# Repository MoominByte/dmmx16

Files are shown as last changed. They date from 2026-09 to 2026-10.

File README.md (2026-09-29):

# BenchScan DMMX16

BenchScan DMMX16 is a digital multimeter switching card inspired by the functional architecture of the SIGLENT SC1016. It provides 16 measurement channels: 12 multipurpose channels and 4 fuse-protected current channels.

## Project status

- Schematic revision: **DRAFT-1**
- File format: **KiCad 10**
- Hierarchical schematic converted and saved
- ERC: **0 errors and 18 off-grid warnings** from the custom MOSFET symbols
- PCB: **220 × 110 mm**, four copper layers, with all 113 footprints placed on the top side
- Preliminary placement completed; routing and manufacturing files have not started

This project is not ready for manufacturing.

## Opening the project

Open `BenchScan_DMMX16.kicad_pro` with KiCad 10. The modern root schematic is `BenchScan_DMMX16.kicad_sch`.

The legacy `.sch` files are retained as conversion sources. The earlier architecture-only draft is preserved under `archive/architecture-notes-draft0/`.

## Architecture

### Control

- Main module: Seeed Studio XIAO ESP32-C6, U1
- D0 / GPIO0: serial data `SER`
- D1 / GPIO1: shift clock `SRCLK`
- D2 / GPIO2: register clock `RCLK`
- D3 / GPIO21: active-low output enable `/OE`
- D4 / GPIO22: direct K17 control
- U2 and U3: two SN74HC595 shift registers powered by the XIAO 3.3 V output
- U2 controls K1-K8 and U3 controls K9-K16

Each relay is driven by a 2N7002K MOSFET with a 100 ohm series gate resistor, a 47 kohm gate pull-down, and a 1N4148W flyback diode. K17 uses the same driver circuit but receives its control signal directly from the XIAO.

### Measurement channels

| Connector | Channels | Purpose |
| --- | --- | --- |
| J1 | CH1-CH4 | Voltage, resistance, frequency, capacitance, diode, continuity, and temperature |
| J2 | CH5-CH8 | Multipurpose measurement and associated SENSE channels |
| J3 | CH9-CH12 | Multipurpose measurement and associated SENSE channels |
| J4 | CH13-CH16 | Current measurement, provisional 500 mA maximum |

Each J1-J4 connector has eight positions at 5.00 mm pitch: one `HI` and one `LO` terminal for each of its four channels.

### Switching

- K1-K16 use normally open contacts.
- K1-K6 route directly to `INPUT_HI` and `COM`.
- K7-K12 are routed through K17.
- With K17 de-energized, K7-K12 are routed to `INPUT_HI` and `COM`.
- With K17 energized, K7-K12 are routed to `SENSE_HI` and `SENSE_LO`.
- The four-wire pairs are CH1+CH7, CH2+CH8, CH3+CH9, CH4+CH10, CH5+CH11, and CH6+CH12.
- K13-K16 route the current channels to `CURRENT_HI` and `CURRENT_LO`.

Firmware must prevent multiple channels from being connected to the same destination bus at the same time, except for one valid four-wire pair.

### Current-channel protection

F1-F4 are Littelfuse `0451.500MRL` fast-acting 500 mA, 125 V fuses. They must not be replaced by 0.1 ohm resistors without a new circuit and safety analysis.

### DMM interface

J5 and the six banana jacks expose:

- `INPUT_HI`
- `COM`
- `SENSE_HI`
- `SENSE_LO`
- `CURRENT_HI`
- `CURRENT_LO`

R50 is a default-fitted 0 ohm link between `CURRENT_LO` and `COM`, with accessible test points planned on both sides.

### Power

- The XIAO is powered through its USB-C connector.
- The barrel jack supplies only the `+5V_RELAY` rail through F6 and Q19.
- USB, logic, and relay grounds are common.
- The external 5 V supply is not connected directly to the XIAO VBUS pin, preventing backfeed into USB.

## Schematic structure

- `01_power_control.kicad_sch`: XIAO, shift registers, and power supply
- `02_relay_drivers.kicad_sch`: 17 relay-coil drivers
- `03_voltage_channels.kicad_sch`: CH1-CH12 and normal/sense selection
- `04_current_dmm_interface.kicad_sch`: CH13-CH16, fuses, and DMM interface

Supporting documents:

- `BOM_AUDIT.md`: bill-of-materials review
- `CONNECTOR_PINOUT.csv`: J1-J4 pin assignments
- `SWITCHING_TRUTH_TABLE.md`: switching truth table
- `PLACEMENT_CONSTRAINTS.md`: mechanical and placement constraints
- `SC1016_REFERENCE.md`: SC1016 reference specifications
- `erc-placement.json`: latest automated ERC report
- `drc-placement.json`: preliminary placement DRC report (routing intentionally incomplete)
- `LIBRARY_SOURCES.md`: footprint provenance and manufacturer references

## Required before routing

1. Align the custom MOSFET symbol pins to eliminate the 18 ERC off-grid warnings.
2. Verify the gate, source, and drain pin mapping of Q1-Q19 against the selected SOT-23 footprint.
3. Mechanically verify the four project-created footprints against physical samples or manufacturer drawings before ordering boards.
4. Confirm voltage limits, creepage and clearance requirements, trace-width rules, and internal plane strategy.
5. Review and refine the preliminary placement, especially edge access and measurement-signal return paths.
6. Complete a manual schematic and PCB review before routing and manufacturing-output generation.

## Warning

The SC1016 ratings are used only as a functional reference. They do not certify the electrical limits of this board. A complete safety and manufacturability review is required before ordering PCBs.

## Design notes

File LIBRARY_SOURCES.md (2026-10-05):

# Component library sources

The project keeps the exact footprints used by the design in local KiCad libraries so the design remains reproducible.

| Part | Project library | Source | Notes |
|---|---|---|---|
| Phoenix Contact 1190370 | `BenchScan_Connectors.pretty` | [Phoenix Contact product data](https://www.phoenixcontact.com/en-pc/products/pcb-terminal-block-lpta-25-8-50-1190370) | Project footprint based on the manufacturer dimensions: 8 positions, 5.00 mm pitch, 1.30 mm PCB holes, 41.5 × 21.35 mm body envelope. |
| Seeed Studio XIAO ESP32-C6 | `Seeed_XIAO.pretty` | [Seeed Studio OPL KiCad Library](https://github.com/Seeed-Studio/OPL_Kicad_Library) | Official `XIAO-ESP32-C6-SMD.kicad_mod` footprint. Pads 15–24 are optional underside module contacts and remain unconnected in this design. |
| Würth Elektronik 691137710006 | `Wurth_Connectors.pretty` | [Würth Elektronik KiCad Library](https://github.com/WurthElektronik/KiCad-Library) | Official footprint and STEP model; model path changed only to use the project-local copy. |
| KEMET/YAGEO UD2-5NE | `BenchScan_Custom.pretty` | [UC2/UD2 datasheet](https://content.kemet.com/datasheets/KEM_R7005_UC2_UD2.pdf) | Project footprint follows the UD2 NU/NE top-view land pattern: 8 SMD pads, 6.74 mm row spacing, 3.2/2.2/2.2 mm column spacing, 0.8 x 1.86 mm pads. |
| Pomona 73099 | `BenchScan_Custom.pretty` | [Pomona 73099 datasheet](https://www.pomonaelectronics.com/files/datasheets/d73099_101.pdf) | Project footprint follows the manufacturer panel/PCB drilling: four common 1.30 mm electrical holes on a 10.16 x 3.80 mm rectangle and one 2.20 mm mechanical hole. |
| Tensility 54-00129 | `BenchScan_Custom.pretty` | [Tensility 54-00129 specification](https://tensility.s3.us-west-2.amazonaws.com/imports/product_spec_sheets/54-00129.pdf) | Project footprint uses the manufacturer PCB layout for terminals A, C and switched terminal B. |
| Littelfuse 0451.500MRL | `BenchScan_Custom.pretty` | [Littelfuse 451/453 datasheet](https://www.littelfuse.com/assetdocs/fuse-451-and-453-datasheet?assetguid=533cd5cc-956c-4243-867f-6ab5a62f6ba1) | Project footprint follows the recommended NANO2 2410 pad layout. |

Imported vendor files should not be geometrically modified without checking the current manufacturer drawing and recording the change here.

## 3D model status

Standard SMD packages use the official KiCad 10 STEP models. Manufacturer STEP models are retained for Phoenix 1190370 and Würth 691137710006.

Project-local files whose names end in `_envelope.wrl` are mechanical-envelope visualization models derived from the documented component dimensions and footprint geometry. They are intentionally simplified and must not be treated as manufacturer cosmetic CAD. Replace them with verified manufacturer STEP files when unrestricted models become available.

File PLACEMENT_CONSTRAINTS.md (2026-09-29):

# PCB placement constraints - preliminary placement

- Outline: **220.0 × 110.0 mm**; four copper layers; components on top only.
- Top edge, left to right within the instrument/power zone: the XIAO USB-C must face the top edge, adjacent to J7 barrel input; J5 and the six DMM banana jacks are also top-edge parts near the XIAO.
- Field connectors J1, J2, J3, J4 must be aligned from left to right on one row. Their relay groups must be directly above them.
- Reserve sufficient edge clearance for USB plug, barrel plug and safety-banana mating bodies before routing.
- Use an uninterrupted internal GND reference plane; keep relay coil returns away from DMM measurement returns and relay-contact paths.
- The current placement is a structured starting point, not a manufacturing release. Do not route or generate manufacturing outputs until the remaining `BOM_AUDIT.md` items, mechanical checks, signal-integrity review, and safety constraints are resolved.
- Current automated status: 113 top-side footprints, 146 nets, zero PCB DRC errors before routing, and 280 expected unrouted connections.

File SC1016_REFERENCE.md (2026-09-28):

# SIGLENT SC1016 reference - DS60030-E02B

This document is a design reference, not a claim that BenchScan DMMX16 already meets the same ratings.

## Functional reference

- 12 multipurpose channels, CH1-CH12: DCV, ACV, 2-wire and 4-wire resistance, capacitance, frequency, diode, continuity, thermocouple and RTD.
- 4 current-only channels, CH13-CH16: DCI and ACI.
- Six 4-wire pairs: CH1 input + CH7 sense, CH2 + CH8, CH3 + CH9, CH4 + CH10, CH5 + CH11, CH6 + CH12.
- Current range in the SC1016 documentation: 2 A range only; continuous current below 2.2 A.

## Published SC1016 reference ratings

| Parameter | SC1016 value |
| --- | --- |
| Maximum AC input | 125 Vrms or 175 Vpeak, 100 kHz |
| AC switched load | 0.3 A, 125 VA resistive |
| Maximum DC input | 110 V |
| DC switched load | 1 A at 30 VDC resistive |
| Maximum switching voltage | 250 VAC / 220 VDC |
| Maximum switching power | 62.5 VA / 30 W |
| Contact resistance | 75 milliohm maximum at 6 VDC, 1 A |
| Actuation | 5 ms maximum on/off |
| Insulation resistance | 1 gigaohm minimum at 500 VDC |

## BenchScan implications

- The functional channel grouping and 4-wire pairing are adopted.
- The electrical ratings are design targets only until verified against the actual UD2-5NE relays, connectors, fuses, PCB clearances, copper geometry and enclosure.
- The selected design retains four Littelfuse 0451.500MRL fast fuses. CH13-CH16 therefore remain provisionally limited to 500 mA and BenchScan must not be labeled as a 2 A scanner.

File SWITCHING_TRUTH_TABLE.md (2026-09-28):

# Switching truth table - DRAFT-1

All K1-K16 signal contacts are normally open. Only the selected relay is energized, except for a deliberate 4-wire pair.

| Mode | Energized channel relay(s) | K17 | DMM destination |
| --- | --- | --- | --- |
| Normal CH1-CH6 | One of K1-K6 | OFF | INPUT_HI / COM |
| Normal CH7-CH12 | One of K7-K12 | OFF | INPUT_HI / COM |
| 4-wire CH1 | K1 + K7 | ON | K1 -> INPUT_HI/COM; K7 -> SENSE_HI/SENSE_LO |
| 4-wire CH2 | K2 + K8 | ON | K2 -> INPUT_HI/COM; K8 -> SENSE_HI/SENSE_LO |
| 4-wire CH3 | K3 + K9 | ON | K3 -> INPUT_HI/COM; K9 -> SENSE_HI/SENSE_LO |
| 4-wire CH4 | K4 + K10 | ON | K4 -> INPUT_HI/COM; K10 -> SENSE_HI/SENSE_LO |
| 4-wire CH5 | K5 + K11 | ON | K5 -> INPUT_HI/COM; K11 -> SENSE_HI/SENSE_LO |
| 4-wire CH6 | K6 + K12 | ON | K6 -> INPUT_HI/COM; K12 -> SENSE_HI/SENSE_LO |
| Current CH13-CH16 | One of K13-K16 | OFF | CURRENT_HI / CURRENT_LO |

Interlock rules: never energize more than one relay on a shared destination bus, except the valid 4-wire pair shown above. Never switch a current channel while a voltage/sense channel is active unless the DMM interface is explicitly designed and verified for that state.

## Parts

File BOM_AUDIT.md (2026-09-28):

# BOM audit — DRAFT-0

The imported BOM is the source of truth for references and manufacturer part numbers below. This starter schematic does not silently add unspecified parts.

## Items consistent with the intended architecture

| Function | BOM evidence |
| --- | --- |
| Main controller | U1 Seeed Studio XIAO ESP32-C6, 113991254 |
| Relay matrix | K1–K17 KEMET UD2-5NE, 5 V DPDT |
| Coil clamps/drivers | D1–D17 1N4148W-13-F; Q1–Q17 2N7002K; 100 R gate series R1–R17; 47 k pull-down R18–R34 |
| Current protection | F1–F4 Littelfuse 0451.500MRL, 500 mA fast 125 V |
| Universal DMM port | J5 six-position terminal, J6/J9/J11 red and J8/J10/J12 black Pomona banana jacks, R50 0 R CURRENT_LO–COM link |
| Power input | J7 5.5/2.1 mm barrel, F6 resettable fuse, Q19 AO3401A, D19 SMBJ5.0A, C7 47 uF |

## User-confirmed architecture

1. U2/U3 run from the XIAO 3V3 output and control K1-K16 through their individual MOSFET drivers.
2. K17 uses a dedicated XIAO GPIO and its existing MOSFET driver, so the two 74HC595 are sufficient.
3. K1-K16 contacts are normally open. K1-K12 are voltage/multipurpose channels; K13-K16 are current channels.
4. K17 selects whether the K7-K12 relay bus is sent to normal INPUT_HI/COM or SENSE_HI/SENSE_LO.
5. Four-wire resistance pairs are CH1+CH7 through CH6+CH12, matching the SC1016 functional reference.
6. F1-F4 remain Littelfuse 0451.500MRL fast-acting 500 mA fuses; they are not replaced by 0.1 ohm resistors.

## Still required before manufacturing release

1. **GPIO validation:** confirm the proposed XIAO pins D0-D4 against ESP32-C6 boot strapping, USB operation and firmware needs. K17 must remain off during reset/boot.
2. **Connector identity:** the user image shows 16 terminals per connector (four channels times four terminals). Confirm manufacturer part 1190370 and footprint pin numbering because the BOM role text also calls it an 8-position connector.
3. **Electrical ratings:** define the promised input limits and required creepage/clearance. The SC1016 reference states 125 Vrms/175 Vpeak AC, 110 VDC and 62.5 VA/30 W, but those values are not automatically valid for this PCB.
4. **Current rating:** the user selected the BOM's 500 mA F1-F4 protection. CH13-CH16 therefore have a provisional 500 mA maximum rating, even though the SC1016 reference permits continuous current below 2.2 A. Verify relay, connector, copper and fault ratings before release.
5. **Physical parts:** obtain verified KiCad symbols/footprints and dimensional drawings for U1, J1-J5, J7 and banana jacks; confirm edge and mating clearances.
6. **Safety switching policy:** firmware interlocks must enforce one active channel per destination bus, and paired closures only for valid 4-wire combinations.

## Explicit draft assumptions

- Relay de-energized is the safe, unselected state.
- R50 is fitted by default, with accessible pads to isolate CURRENT_LO from COM when a DMM requires it.
- J1–J4 are placed left-to-right. Relay banks sit immediately above their associated field connector.
- USB-C of U1, J7, J5, and six banana jacks share the top board edge zone; no components are planned on the bottom side.

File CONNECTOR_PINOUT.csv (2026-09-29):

Connector | Pin | Net | Channel | Function
J1 | 1 | CH1_HI | CH1 | HI
J1 | 2 | CH1_LO | CH1 | LO
J1 | 3 | CH2_HI | CH2 | HI
J1 | 4 | CH2_LO | CH2 | LO
J1 | 5 | CH3_HI | CH3 | HI
J1 | 6 | CH3_LO | CH3 | LO
J1 | 7 | CH4_HI | CH4 | HI
J1 | 8 | CH4_LO | CH4 | LO
J2 | 1 | CH5_HI | CH5 | HI
J2 | 2 | CH5_LO | CH5 | LO
J2 | 3 | CH6_HI | CH6 | HI
J2 | 4 | CH6_LO | CH6 | LO
J2 | 5 | CH7_HI | CH7 | HI
J2 | 6 | CH7_LO | CH7 | LO
J2 | 7 | CH8_HI | CH8 | HI
J2 | 8 | CH8_LO | CH8 | LO
J3 | 1 | CH9_HI | CH9 | HI
J3 | 2 | CH9_LO | CH9 | LO
J3 | 3 | CH10_HI | CH10 | HI
J3 | 4 | CH10_LO | CH10 | LO
J3 | 5 | CH11_HI | CH11 | HI
J3 | 6 | CH11_LO | CH11 | LO
J3 | 7 | CH12_HI | CH12 | HI
J3 | 8 | CH12_LO | CH12 | LO
J4 | 1 | CH13_HI | CH13 | CURRENT HI
J4 | 2 | CH13_LO | CH13 | CURRENT LO
J4 | 3 | CH14_HI | CH14 | CURRENT HI
J4 | 4 | CH14_LO | CH14 | CURRENT LO
J4 | 5 | CH15_HI | CH15 | CURRENT HI
J4 | 6 | CH15_LO | CH15 | CURRENT LO
J4 | 7 | CH16_HI | CH16 | CURRENT HI
J4 | 8 | CH16_LO | CH16 | CURRENT LO

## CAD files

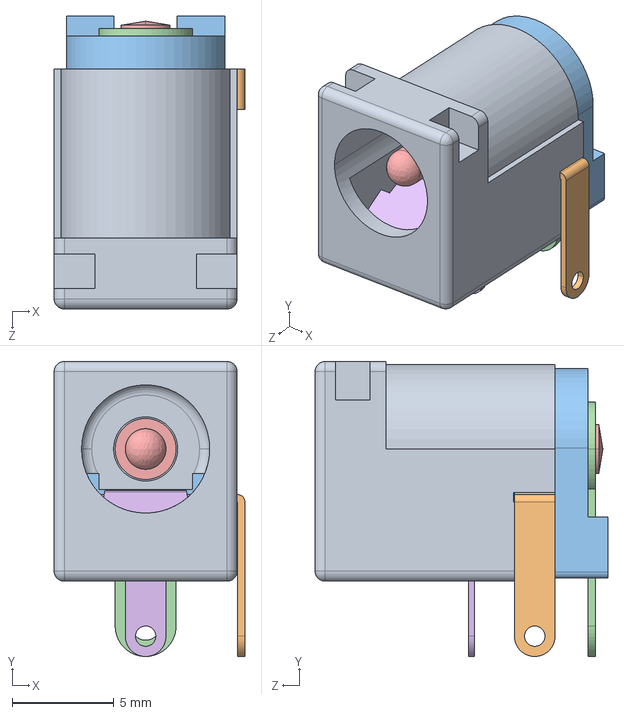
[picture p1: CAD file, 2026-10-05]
54-00129.STEP
9.38 x 14.5 x 14.4 mm

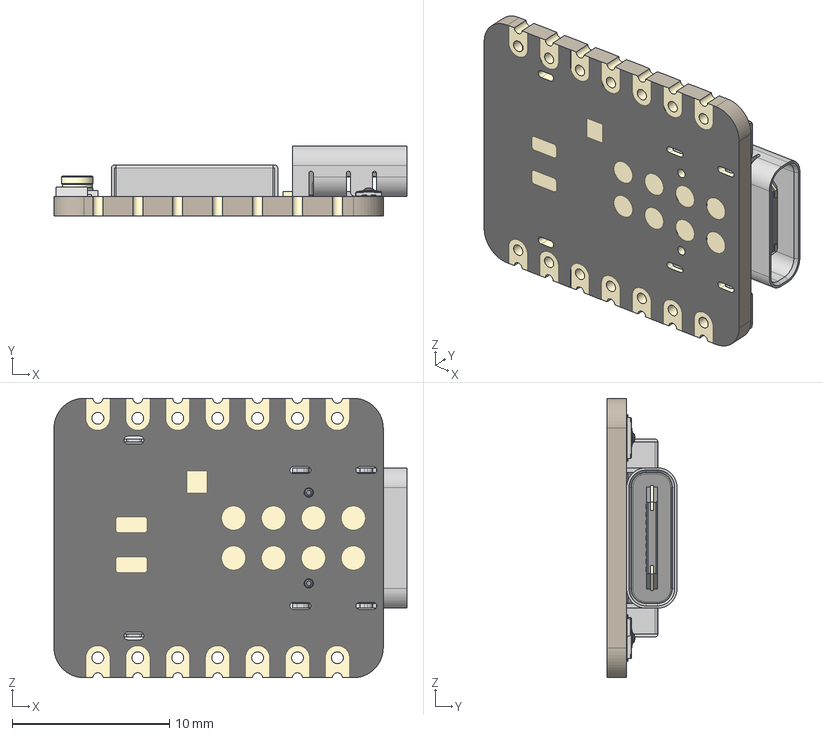
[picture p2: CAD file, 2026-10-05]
Seeed Studio XIAO ESP32-C6.step
22.5 x 4.46 x 17.8 mm
BOSS-EXTRUDE14_8_
BOSS-EXTRUDE7_4_
BOSS-EXTRUDE7_3_
BOSS-EXTRUDE14_4_
BOSS-EXTRUDE14_2_
BOSS-EXTRUDE14_11_
BOSS-EXTRUDE7_7_
BOSS-EXTRUDE14_9_
BOSS-EXTRUDE14_3_
BOSS-EXTRUDE14_7_
MIRROR2
BOSS-EXTRUDE14_5_
BOSS-EXTRUDE14_12_
BOSS-EXTRUDE7_8_
BOSS-EXTRUDE7_1_
BOSS-EXTRUDE14_10_
BOSS-EXTRUDE7_9_
BOSS-EXTRUDE14_6_
BOSS-EXTRUDE14_1_
BOSS-EXTRUDE7_6_
BOSS-EXTRUDE7_2_
CUT-EXTRUDE5
BOSS-EXTRUDE7_5_
U.FL Connector v1
Shield
SKTAAAE010 x 2
KH5220-A36 (Ceramic Antenna) v2

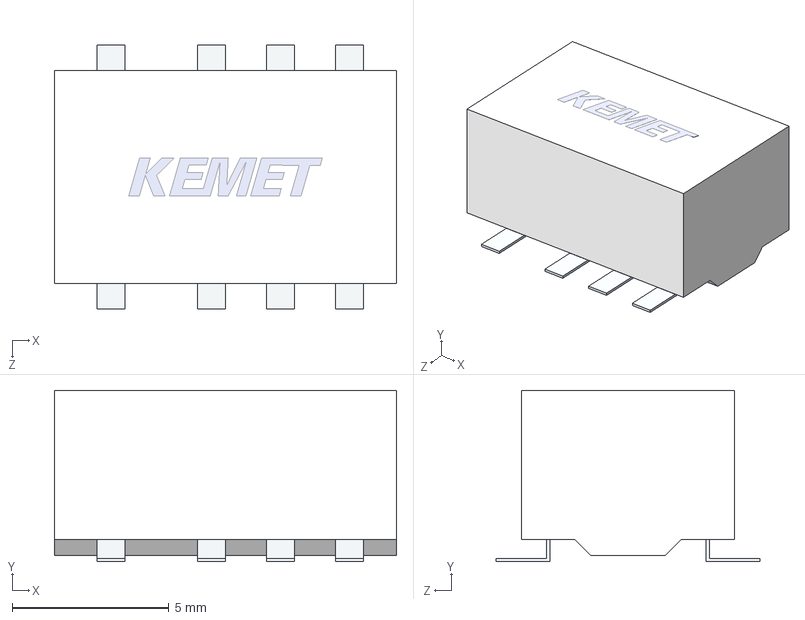
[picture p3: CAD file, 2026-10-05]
UD2-5NE.stp
10.9 x 5.46 x 8.40 mm

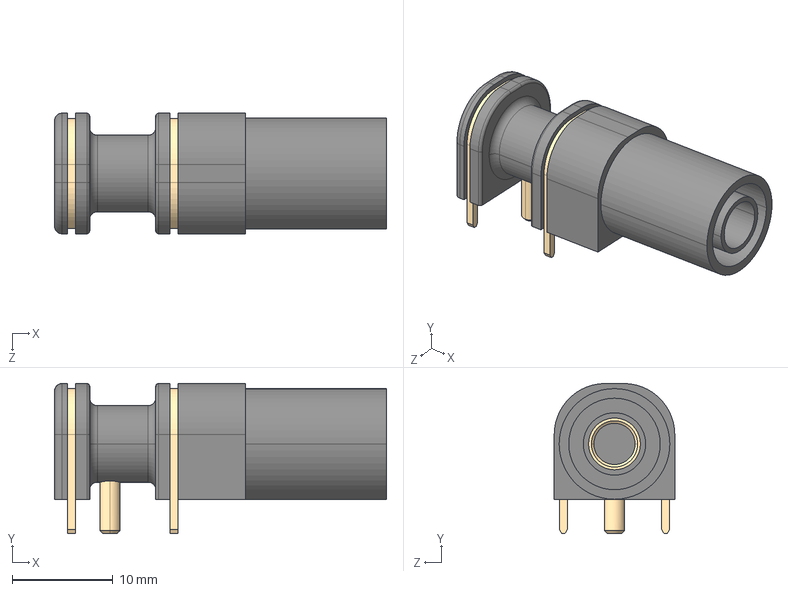
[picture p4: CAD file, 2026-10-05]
73099-0.stp
33.0 x 14.9 x 12.0 mm

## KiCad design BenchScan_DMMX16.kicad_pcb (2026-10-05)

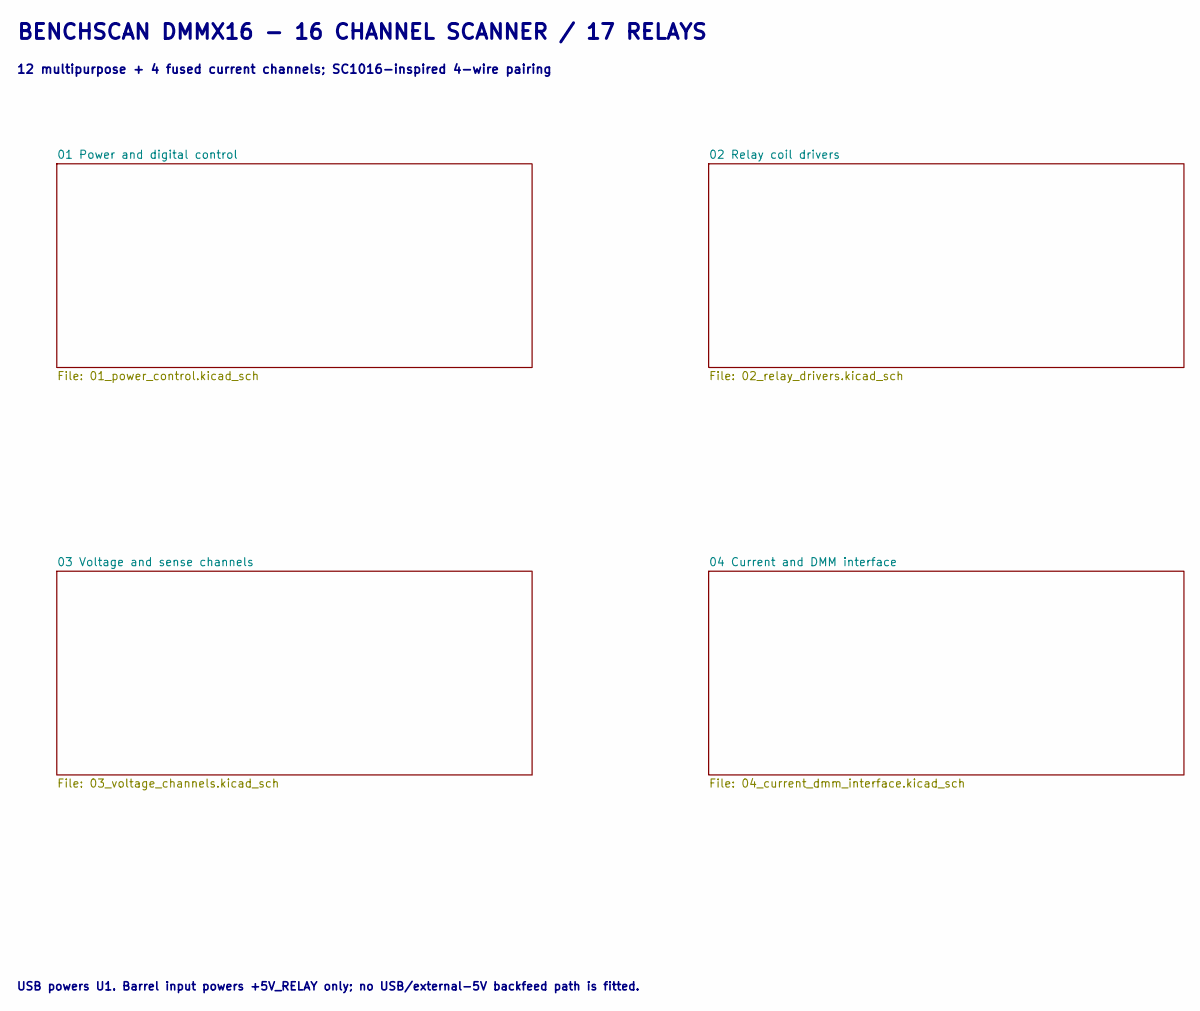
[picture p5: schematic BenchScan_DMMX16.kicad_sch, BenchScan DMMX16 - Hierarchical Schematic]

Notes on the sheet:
12 multipurpose + 4 fused current channels; SC1016-inspired 4-wire pairing
USB powers U1. Barrel input powers +5V_RELAY only; no USB/external-5V backfeed path is fitted.
BENCHSCAN DMMX16 - 16 CHANNEL SCANNER / 17 RELAYS

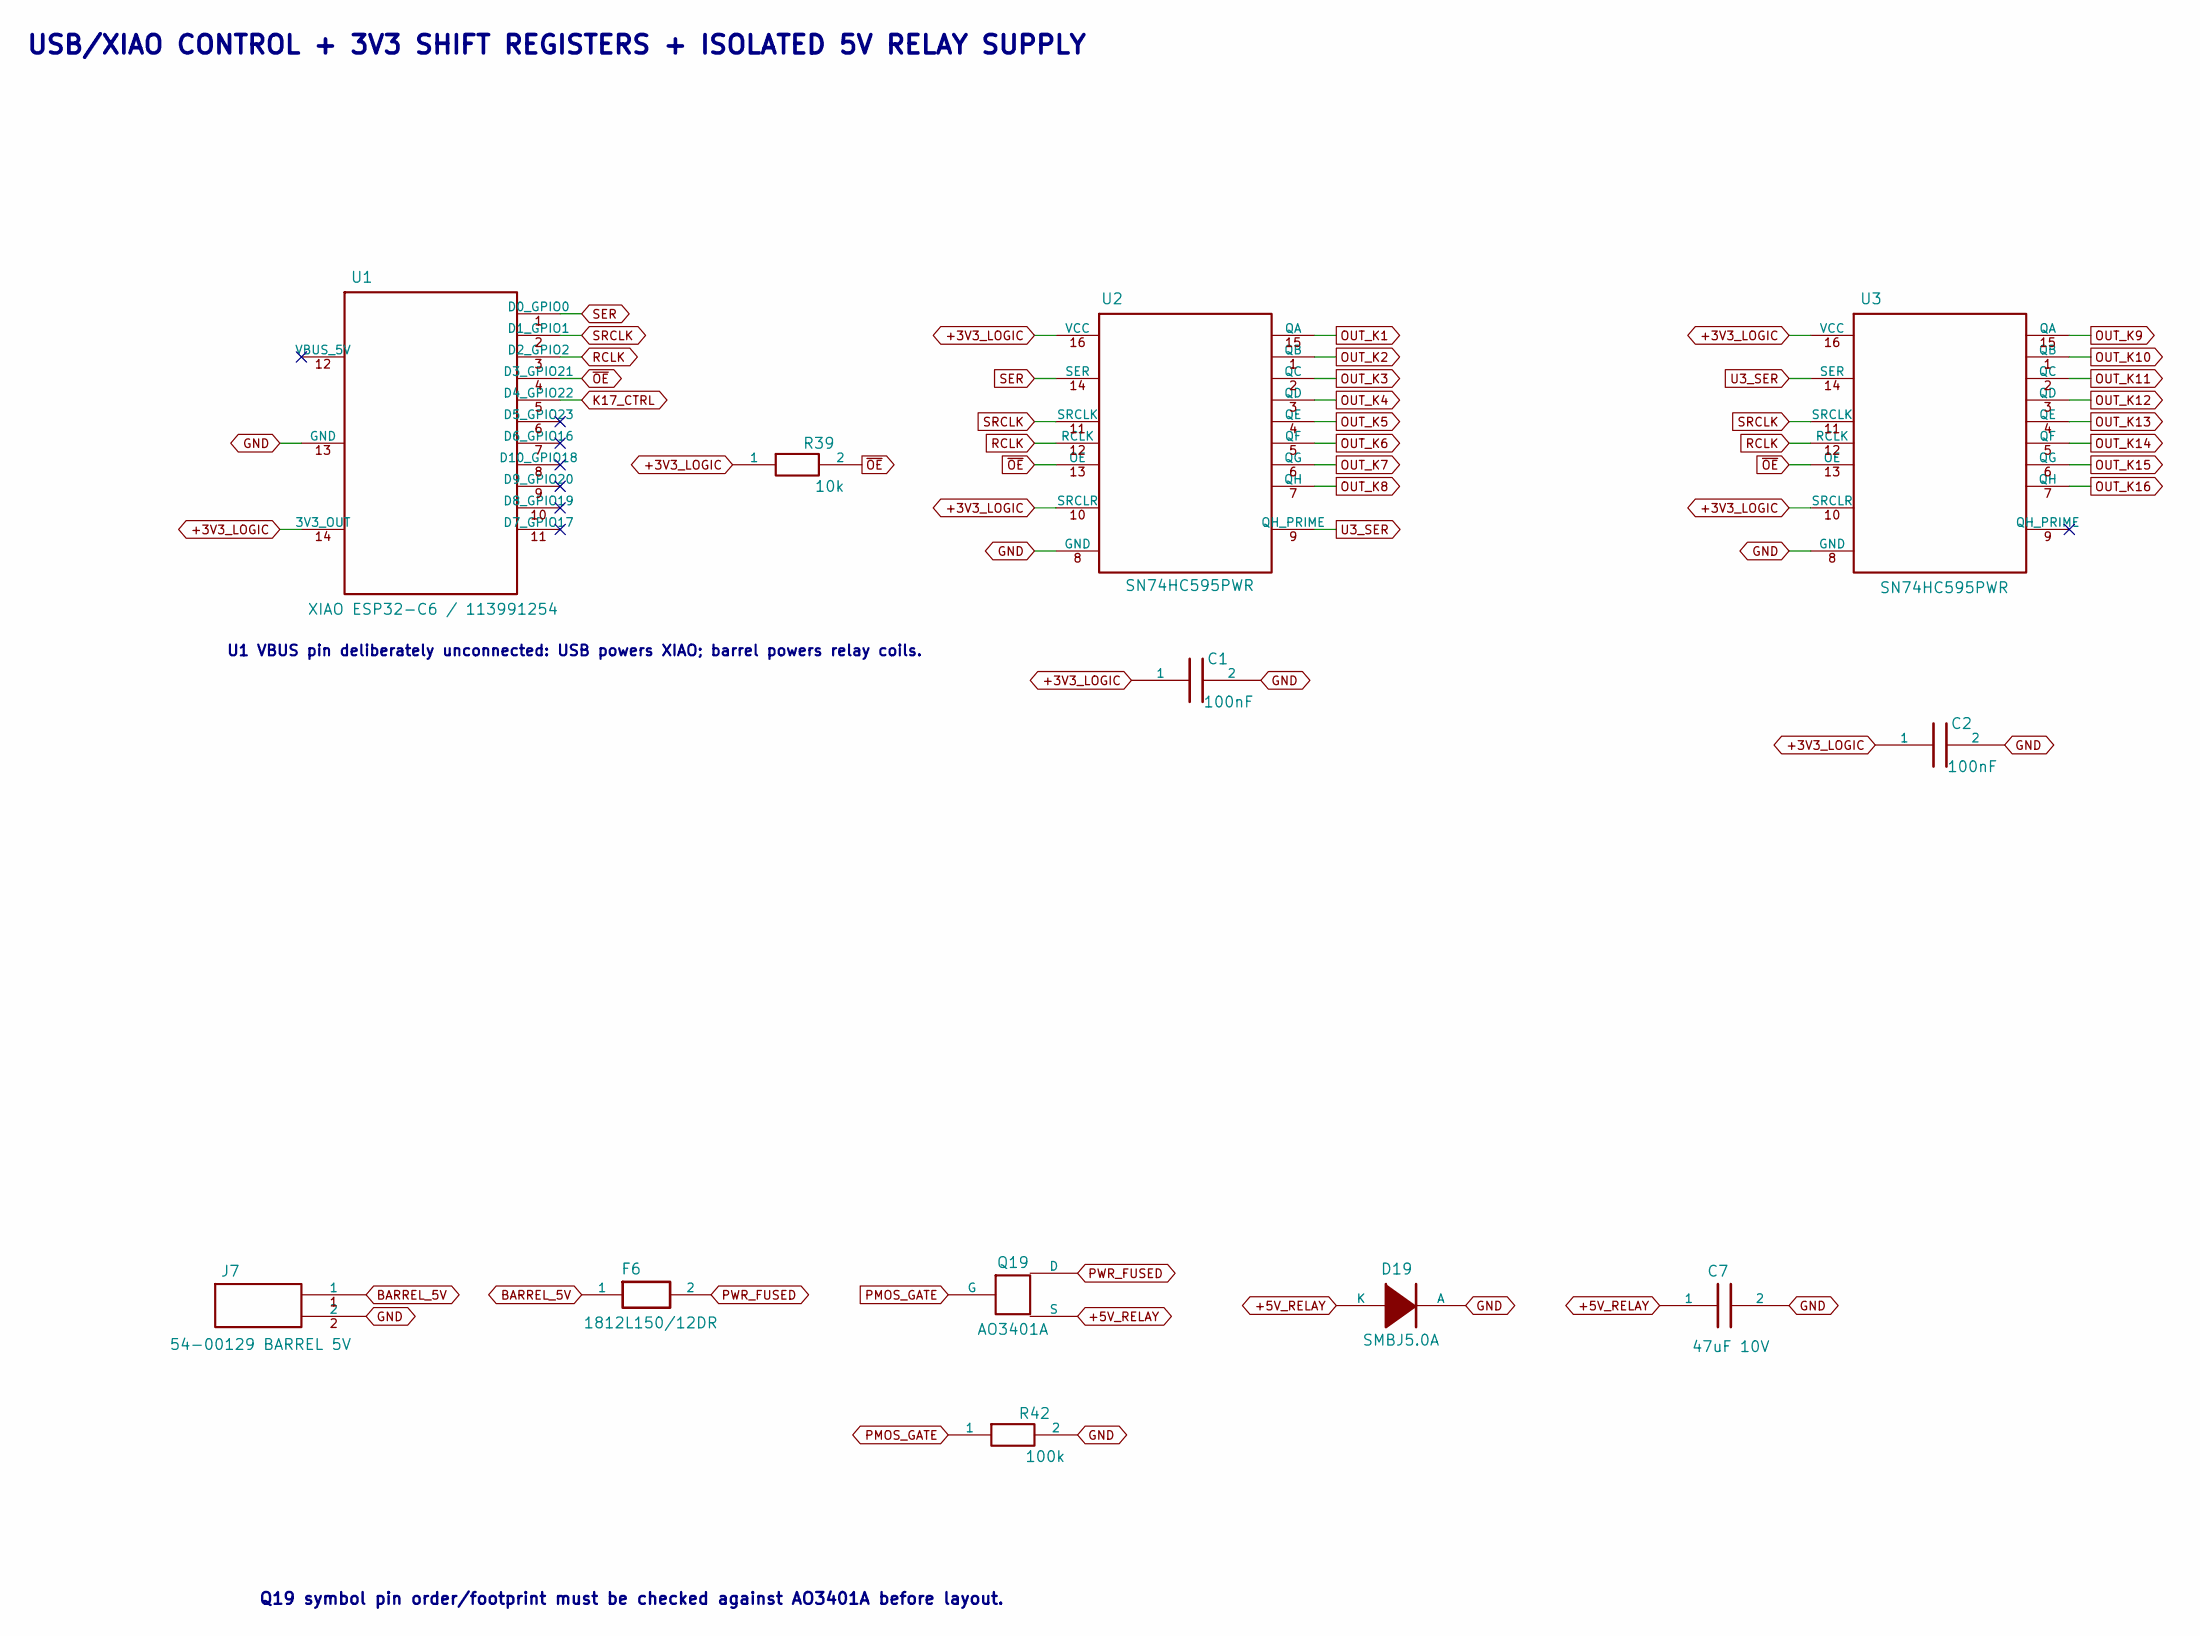
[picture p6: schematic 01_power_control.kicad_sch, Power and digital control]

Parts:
C1, C2: 100nF; C_0603_1608Metric
C7: 47uF 10V; C_1210_3225Metric
D19: SMBJ5.0A; D_SMB
F6: 1812L150/12DR; Fuse_1812_4532Metric
J7: 54-00129 BARREL 5V; Tensility_54-00129_DCJack
Q19: AO3401A; SOT-23
R39: 10k; R_0603_1608Metric
R42: 100k; R_0603_1608Metric
U1: XIAO ESP32-C6 / 113991254; XIAO-ESP32-C6-SMD
U2, U3: SN74HC595PWR; TSSOP-16_4.4x5mm_P0.65mm

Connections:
+3V3_LOGIC: C1.1, C2.1, R39.1, U1.14 (3V3_OUT), U2.10 (SRCLR), U2.16 (VCC), U3.10 (SRCLR), U3.16 (VCC)
+5V_RELAY: C7.1, D19.1 (K), Q19.2 (S); also elsewhere on the board
BARREL_5V: F6.1, J7.1
GND: C1.2, C2.2, C7.2, D19.2 (A), J7.2, R42.2, U1.13 (GND), U2.8 (GND), U3.8 (GND); also elsewhere on the board
K17_CTRL: U1.5 (D4_GPIO22); also elsewhere on the board
OUT_K1: U2.15 (QA); also elsewhere on the board
OUT_K2: U2.1 (QB); also elsewhere on the board
OUT_K3: U2.2 (QC); also elsewhere on the board
OUT_K4: U2.3 (QD); also elsewhere on the board
OUT_K5: U2.4 (QE); also elsewhere on the board
OUT_K6: U2.5 (QF); also elsewhere on the board
OUT_K7: U2.6 (QG); also elsewhere on the board
OUT_K8: U2.7 (QH); also elsewhere on the board
OUT_K9: U3.15 (QA); also elsewhere on the board
OUT_K10: U3.1 (QB); also elsewhere on the board
OUT_K11: U3.2 (QC); also elsewhere on the board
OUT_K12: U3.3 (QD); also elsewhere on the board
OUT_K13: U3.4 (QE); also elsewhere on the board
OUT_K14: U3.5 (QF); also elsewhere on the board
OUT_K15: U3.6 (QG); also elsewhere on the board
OUT_K16: U3.7 (QH); also elsewhere on the board
PMOS_GATE: Q19.1 (G), R42.1
PWR_FUSED: F6.2, Q19.3 (D)
RCLK: U1.3 (D2_GPIO2), U2.12 (RCLK), U3.12 (RCLK)
SER: U1.1 (D0_GPIO0), U2.14 (SER)
SRCLK: U1.2 (D1_GPIO1), U2.11 (SRCLK), U3.11 (SRCLK)
U3_SER: U2.9 (QH_PRIME), U3.14 (SER)
~OE: R39.2, U1.4 (D3_GPIO21), U2.13 (OE), U3.13 (OE)

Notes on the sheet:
USB/XIAO CONTROL + 3V3 SHIFT REGISTERS + ISOLATED 5V RELAY SUPPLY
U1 VBUS pin deliberately unconnected: USB powers XIAO; barrel powers relay coils.
Q19 symbol pin order/footprint must be checked against AO3401A before layout.

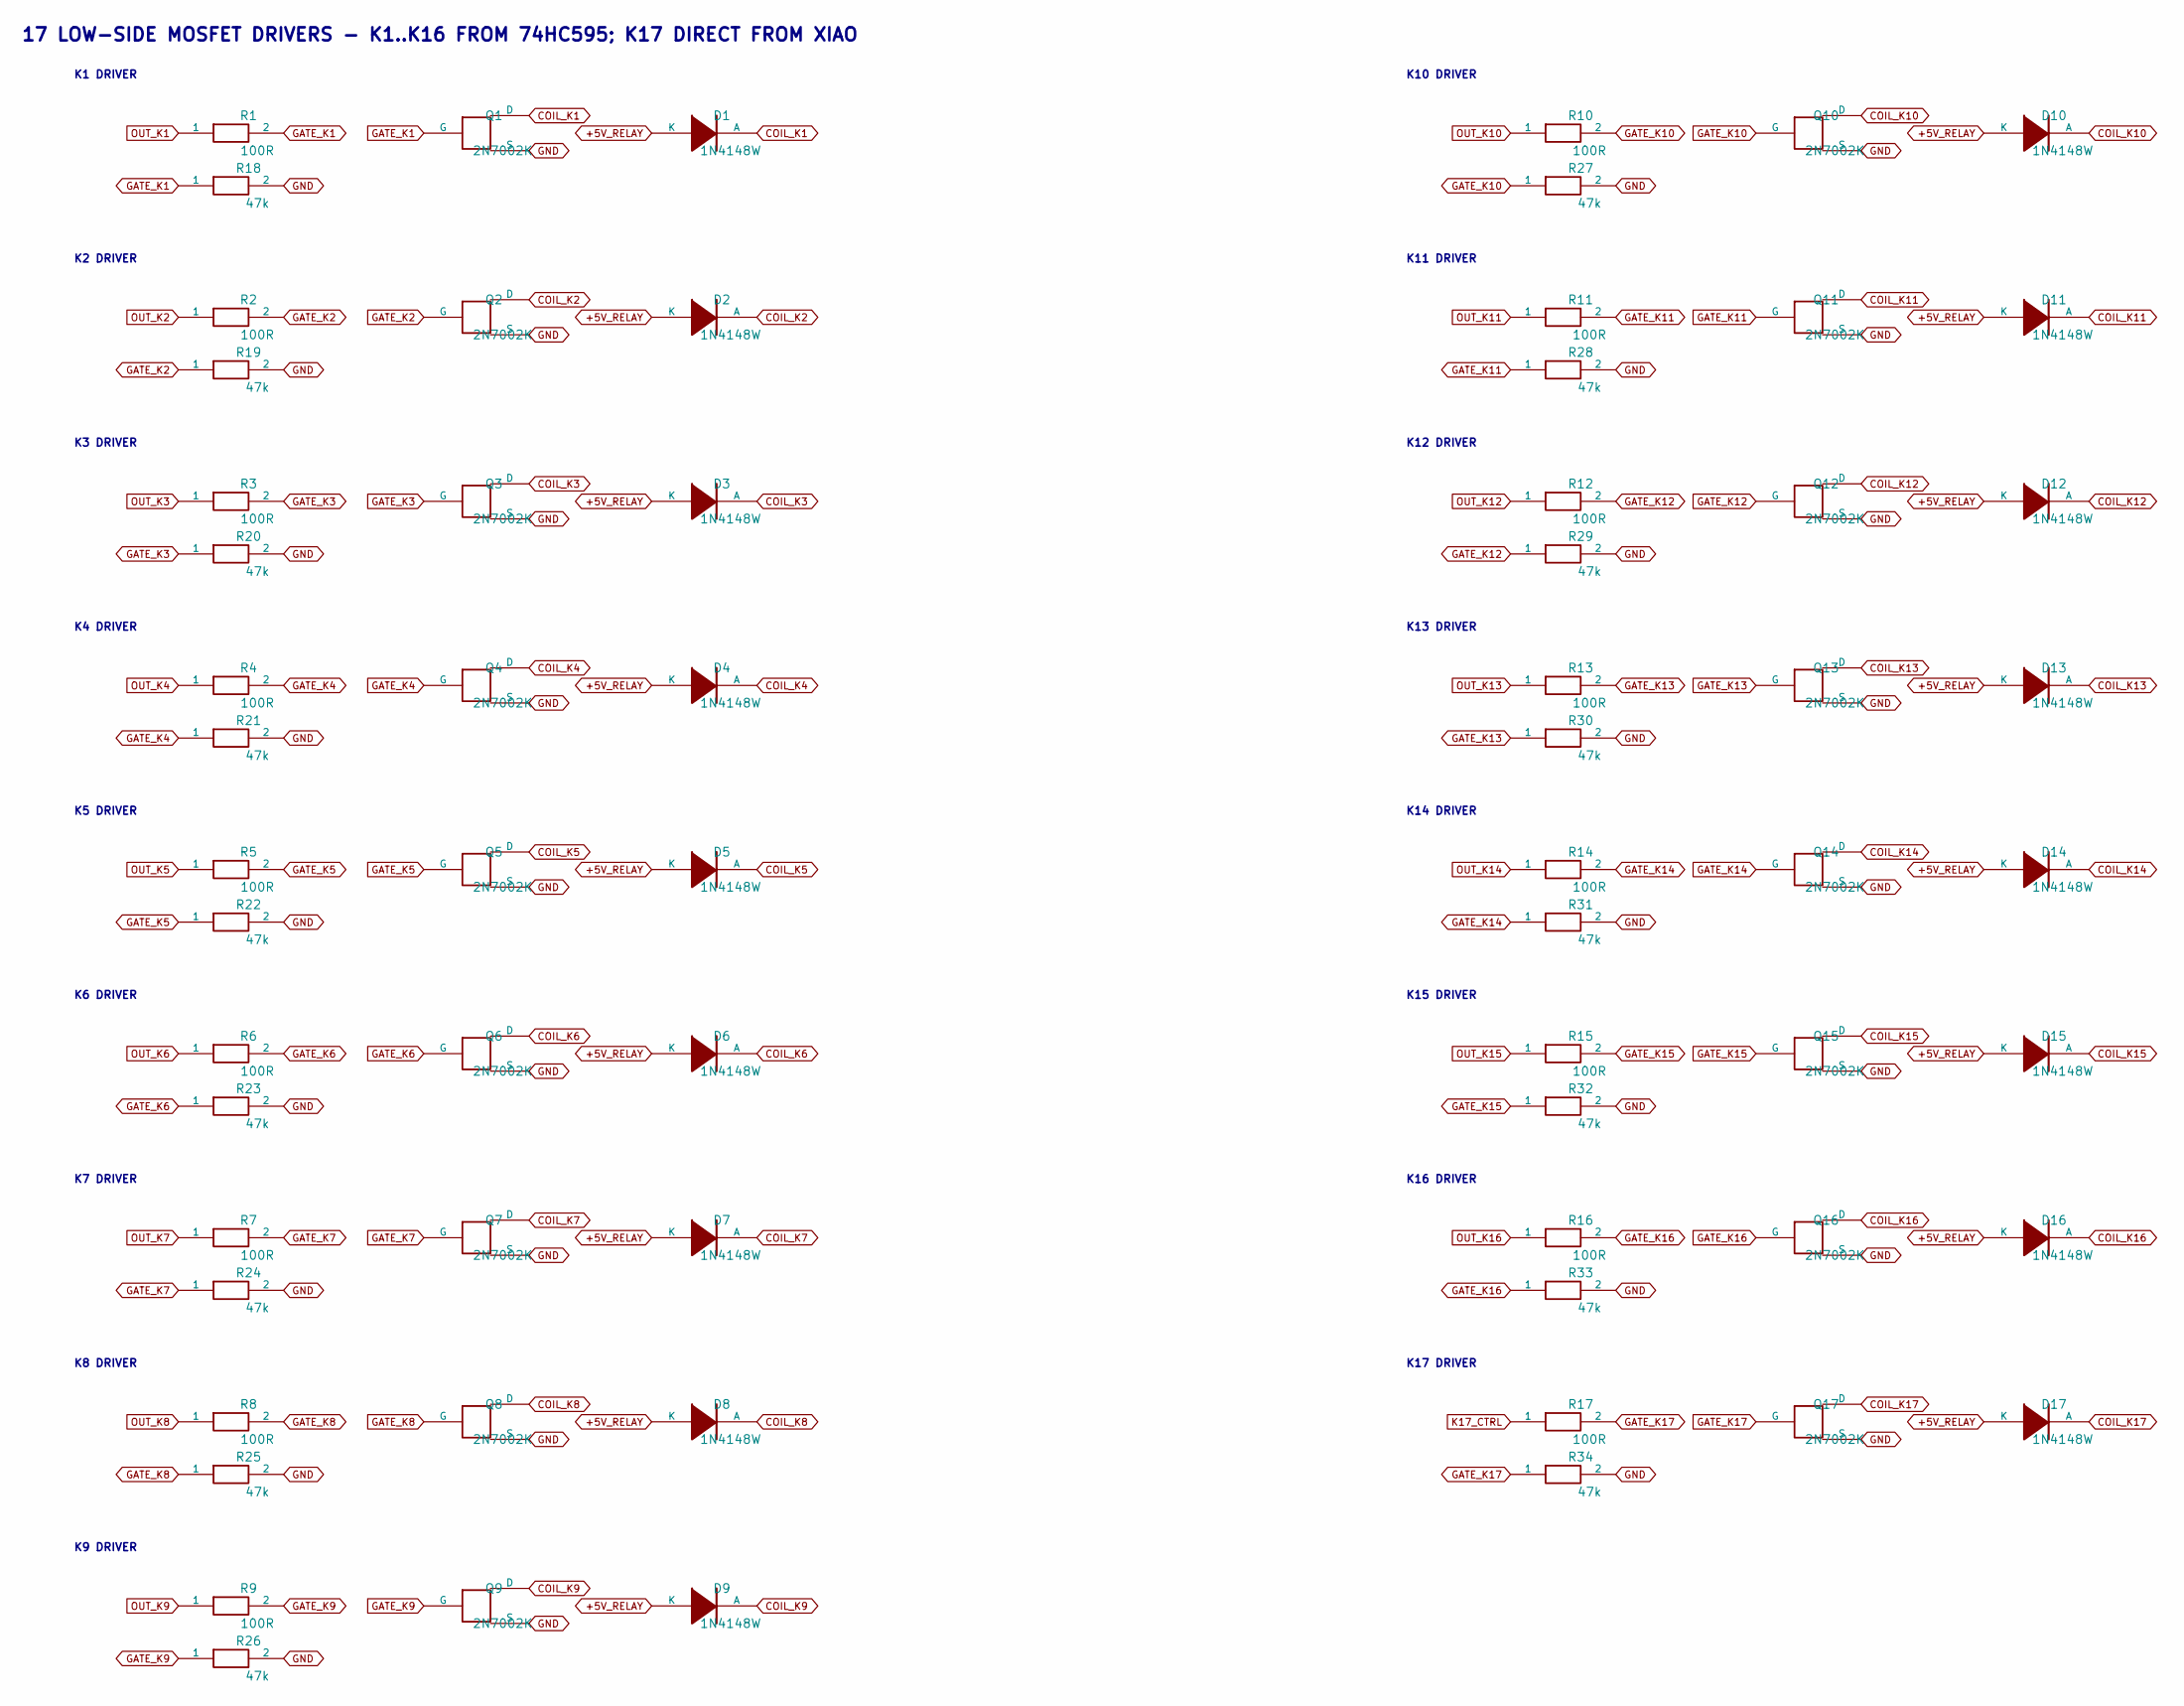
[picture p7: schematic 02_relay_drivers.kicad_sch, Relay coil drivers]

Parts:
D1, D2, D3, D4, D5, D6, D7, D8, D9, D10, D11, D12, D13, D14, D15, D16, D17: 1N4148W; D_SOD-123
Q1, Q2, Q3, Q4, Q5, Q6, Q7, Q8, Q9, Q10, Q11, Q12, Q13, Q14, Q15, Q16, Q17: 2N7002K; SOT-23
R1, R2, R3, R4, R5, R6, R7, R8, R9, R10, R11, R12, R13, R14, R15, R16, R17: 100R; R_0603_1608Metric
R18, R19, R20, R21, R22, R23, R24, R25, R26, R27, R28, R29, R30, R31, R32, R33, R34: 47k; R_0603_1608Metric

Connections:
+5V_RELAY: D1.1 (K), D2.1 (K), D3.1 (K), D4.1 (K), D5.1 (K), D6.1 (K), D7.1 (K), D8.1 (K), D9.1 (K), D10.1 (K), D11.1 (K), D12.1 (K), D13.1 (K), D14.1 (K), D15.1 (K), D16.1 (K), D17.1 (K); also elsewhere on the board
COIL_K1: D1.2 (A), Q1.3 (D); also elsewhere on the board
COIL_K2: D2.2 (A), Q2.3 (D); also elsewhere on the board
COIL_K3: D3.2 (A), Q3.3 (D); also elsewhere on the board
COIL_K4: D4.2 (A), Q4.3 (D); also elsewhere on the board
COIL_K5: D5.2 (A), Q5.3 (D); also elsewhere on the board
COIL_K6: D6.2 (A), Q6.3 (D); also elsewhere on the board
COIL_K7: D7.2 (A), Q7.3 (D); also elsewhere on the board
COIL_K8: D8.2 (A), Q8.3 (D); also elsewhere on the board
COIL_K9: D9.2 (A), Q9.3 (D); also elsewhere on the board
COIL_K10: D10.2 (A), Q10.3 (D); also elsewhere on the board
COIL_K11: D11.2 (A), Q11.3 (D); also elsewhere on the board
COIL_K12: D12.2 (A), Q12.3 (D); also elsewhere on the board
COIL_K13: D13.2 (A), Q13.3 (D); also elsewhere on the board
COIL_K14: D14.2 (A), Q14.3 (D); also elsewhere on the board
COIL_K15: D15.2 (A), Q15.3 (D); also elsewhere on the board
COIL_K16: D16.2 (A), Q16.3 (D); also elsewhere on the board
COIL_K17: D17.2 (A), Q17.3 (D); also elsewhere on the board
GATE_K1: Q1.1 (G), R1.2, R18.1
GATE_K2: Q2.1 (G), R2.2, R19.1
GATE_K3: Q3.1 (G), R3.2, R20.1
GATE_K4: Q4.1 (G), R4.2, R21.1
GATE_K5: Q5.1 (G), R5.2, R22.1
GATE_K6: Q6.1 (G), R6.2, R23.1
GATE_K7: Q7.1 (G), R7.2, R24.1
GATE_K8: Q8.1 (G), R8.2, R25.1
GATE_K9: Q9.1 (G), R9.2, R26.1
GATE_K10: Q10.1 (G), R10.2, R27.1
GATE_K11: Q11.1 (G), R11.2, R28.1
GATE_K12: Q12.1 (G), R12.2, R29.1
GATE_K13: Q13.1 (G), R13.2, R30.1
GATE_K14: Q14.1 (G), R14.2, R31.1
GATE_K15: Q15.1 (G), R15.2, R32.1
GATE_K16: Q16.1 (G), R16.2, R33.1
GATE_K17: Q17.1 (G), R17.2, R34.1
GND: Q1.2 (S), Q2.2 (S), Q3.2 (S), Q4.2 (S), Q5.2 (S), Q6.2 (S), Q7.2 (S), Q8.2 (S), Q9.2 (S), Q10.2 (S), Q11.2 (S), Q12.2 (S), Q13.2 (S), Q14.2 (S), Q15.2 (S), Q16.2 (S), Q17.2 (S), R18.2, R19.2, R20.2, R21.2, R22.2, R23.2, R24.2, R25.2, R26.2, R27.2, R28.2, R29.2, R30.2, R31.2, R32.2, R33.2, R34.2; also elsewhere on the board
K17_CTRL: R17.1; also elsewhere on the board
OUT_K1: R1.1; also elsewhere on the board
OUT_K2: R2.1; also elsewhere on the board
OUT_K3: R3.1; also elsewhere on the board
OUT_K4: R4.1; also elsewhere on the board
OUT_K5: R5.1; also elsewhere on the board
OUT_K6: R6.1; also elsewhere on the board
OUT_K7: R7.1; also elsewhere on the board
OUT_K8: R8.1; also elsewhere on the board
OUT_K9: R9.1; also elsewhere on the board
OUT_K10: R10.1; also elsewhere on the board
OUT_K11: R11.1; also elsewhere on the board
OUT_K12: R12.1; also elsewhere on the board
OUT_K13: R13.1; also elsewhere on the board
OUT_K14: R14.1; also elsewhere on the board
OUT_K15: R15.1; also elsewhere on the board
OUT_K16: R16.1; also elsewhere on the board

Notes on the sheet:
K17 DRIVER
K9 DRIVER
K10 DRIVER
K2 DRIVER
K15 DRIVER
K3 DRIVER
K12 DRIVER
K6 DRIVER
K13 DRIVER
K7 DRIVER
K14 DRIVER
K8 DRIVER
K5 DRIVER
K4 DRIVER
K11 DRIVER
K1 DRIVER
17 LOW-SIDE MOSFET DRIVERS - K1..K16 FROM 74HC595; K17 DIRECT FROM XIAO
K16 DRIVER

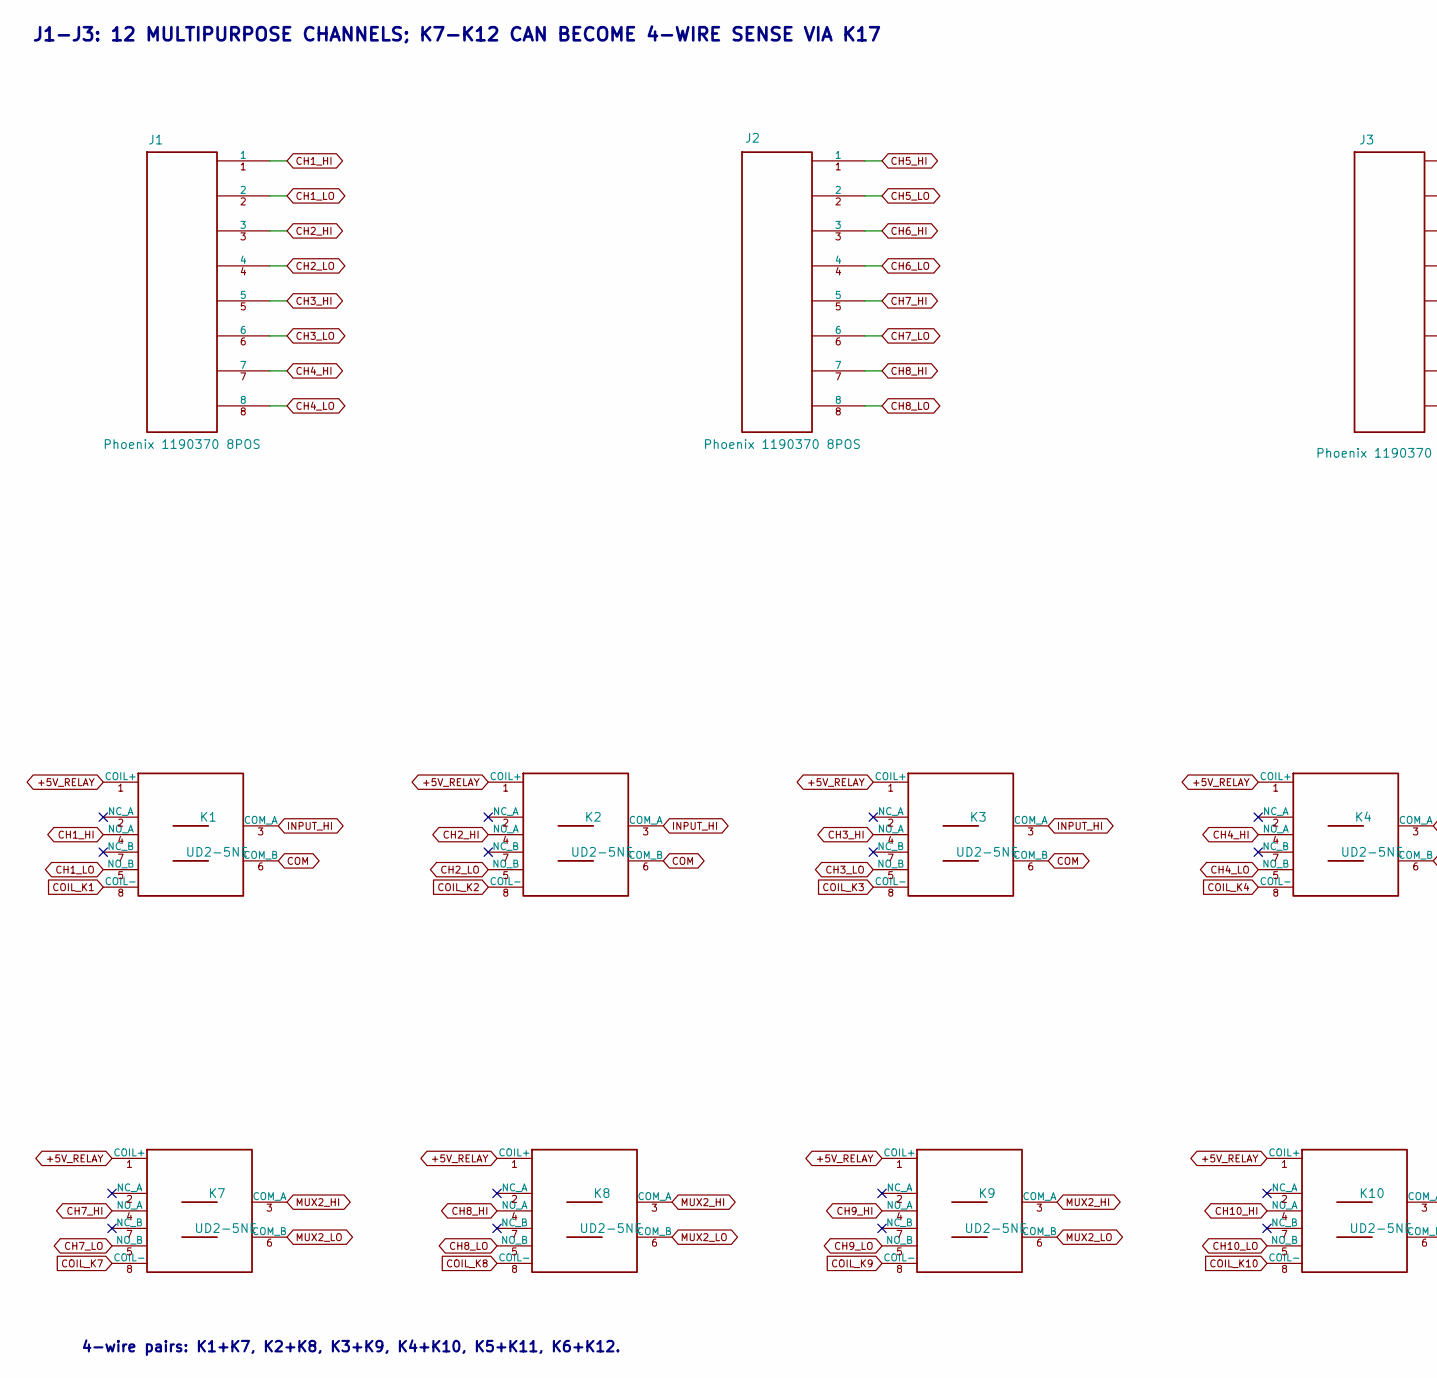
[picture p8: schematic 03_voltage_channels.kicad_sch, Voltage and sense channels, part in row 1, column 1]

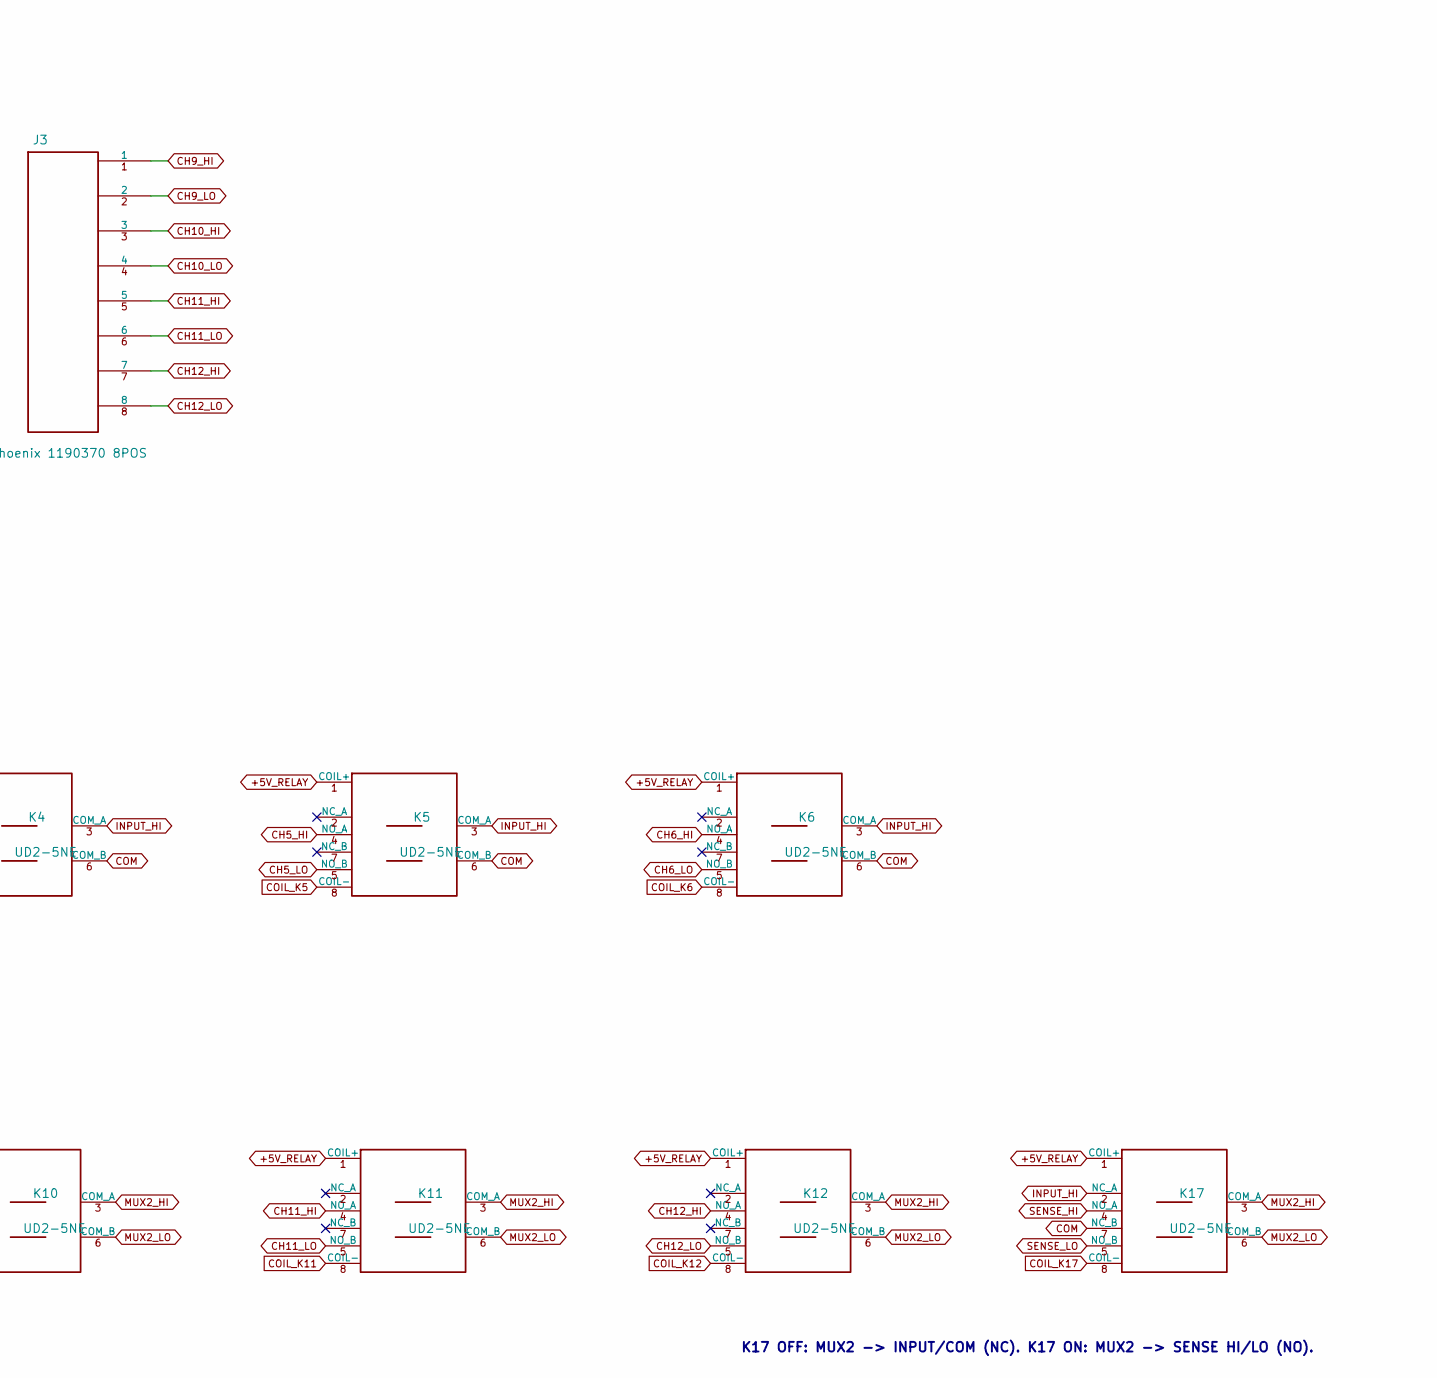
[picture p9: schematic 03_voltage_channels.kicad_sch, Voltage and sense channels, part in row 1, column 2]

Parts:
J1, J2, J3: Phoenix 1190370 8POS; Phoenix_1190370_LPTA-2.5-8-5.0_16THT_Paired
K1, K2, K3, K4, K5, K6, K7, K8, K9, K10, K11, K12, K17: UD2-5NE; Relay_KEMET_UD2_NE

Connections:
+5V_RELAY: K1.1 (COIL+), K2.1 (COIL+), K3.1 (COIL+), K4.1 (COIL+), K5.1 (COIL+), K6.1 (COIL+), K7.1 (COIL+), K8.1 (COIL+), K9.1 (COIL+), K10.1 (COIL+), K11.1 (COIL+), K12.1 (COIL+), K17.1 (COIL+); also elsewhere on the board
CH1_HI: J1.1, K1.4 (NO_A)
CH1_LO: J1.2, K1.5 (NO_B)
CH2_HI: J1.3, K2.4 (NO_A)
CH2_LO: J1.4, K2.5 (NO_B)
CH3_HI: J1.5, K3.4 (NO_A)
CH3_LO: J1.6, K3.5 (NO_B)
CH4_HI: J1.7, K4.4 (NO_A)
CH4_LO: J1.8, K4.5 (NO_B)
CH5_HI: J2.1, K5.4 (NO_A)
CH5_LO: J2.2, K5.5 (NO_B)
CH6_HI: J2.3, K6.4 (NO_A)
CH6_LO: J2.4, K6.5 (NO_B)
CH7_HI: J2.5, K7.4 (NO_A)
CH7_LO: J2.6, K7.5 (NO_B)
CH8_HI: J2.7, K8.4 (NO_A)
CH8_LO: J2.8, K8.5 (NO_B)
CH9_HI: J3.1, K9.4 (NO_A)
CH9_LO: J3.2, K9.5 (NO_B)
CH10_HI: J3.3, K10.4 (NO_A)
CH10_LO: J3.4, K10.5 (NO_B)
CH11_HI: J3.5, K11.4 (NO_A)
CH11_LO: J3.6, K11.5 (NO_B)
CH12_HI: J3.7, K12.4 (NO_A)
CH12_LO: J3.8, K12.5 (NO_B)
COIL_K1: K1.8 (COIL-); also elsewhere on the board
COIL_K2: K2.8 (COIL-); also elsewhere on the board
COIL_K3: K3.8 (COIL-); also elsewhere on the board
COIL_K4: K4.8 (COIL-); also elsewhere on the board
COIL_K5: K5.8 (COIL-); also elsewhere on the board
COIL_K6: K6.8 (COIL-); also elsewhere on the board
COIL_K7: K7.8 (COIL-); also elsewhere on the board
COIL_K8: K8.8 (COIL-); also elsewhere on the board
COIL_K9: K9.8 (COIL-); also elsewhere on the board
COIL_K10: K10.8 (COIL-); also elsewhere on the board
COIL_K11: K11.8 (COIL-); also elsewhere on the board
COIL_K12: K12.8 (COIL-); also elsewhere on the board
COIL_K17: K17.8 (COIL-); also elsewhere on the board
COM: K1.6 (COM_B), K2.6 (COM_B), K3.6 (COM_B), K4.6 (COM_B), K5.6 (COM_B), K6.6 (COM_B), K17.7 (NC_B); also elsewhere on the board
INPUT_HI: K1.3 (COM_A), K2.3 (COM_A), K3.3 (COM_A), K4.3 (COM_A), K5.3 (COM_A), K6.3 (COM_A), K17.2 (NC_A); also elsewhere on the board
MUX2_HI: K7.3 (COM_A), K8.3 (COM_A), K9.3 (COM_A), K10.3 (COM_A), K11.3 (COM_A), K12.3 (COM_A), K17.3 (COM_A)
MUX2_LO: K7.6 (COM_B), K8.6 (COM_B), K9.6 (COM_B), K10.6 (COM_B), K11.6 (COM_B), K12.6 (COM_B), K17.6 (COM_B)
SENSE_HI: K17.4 (NO_A); also elsewhere on the board
SENSE_LO: K17.5 (NO_B); also elsewhere on the board

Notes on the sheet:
4-wire pairs: K1+K7, K2+K8, K3+K9, K4+K10, K5+K11, K6+K12.
K17 OFF: MUX2 -> INPUT/COM (NC). K17 ON: MUX2 -> SENSE HI/LO (NO).
J1-J3: 12 MULTIPURPOSE CHANNELS; K7-K12 CAN BECOME 4-WIRE SENSE VIA K17

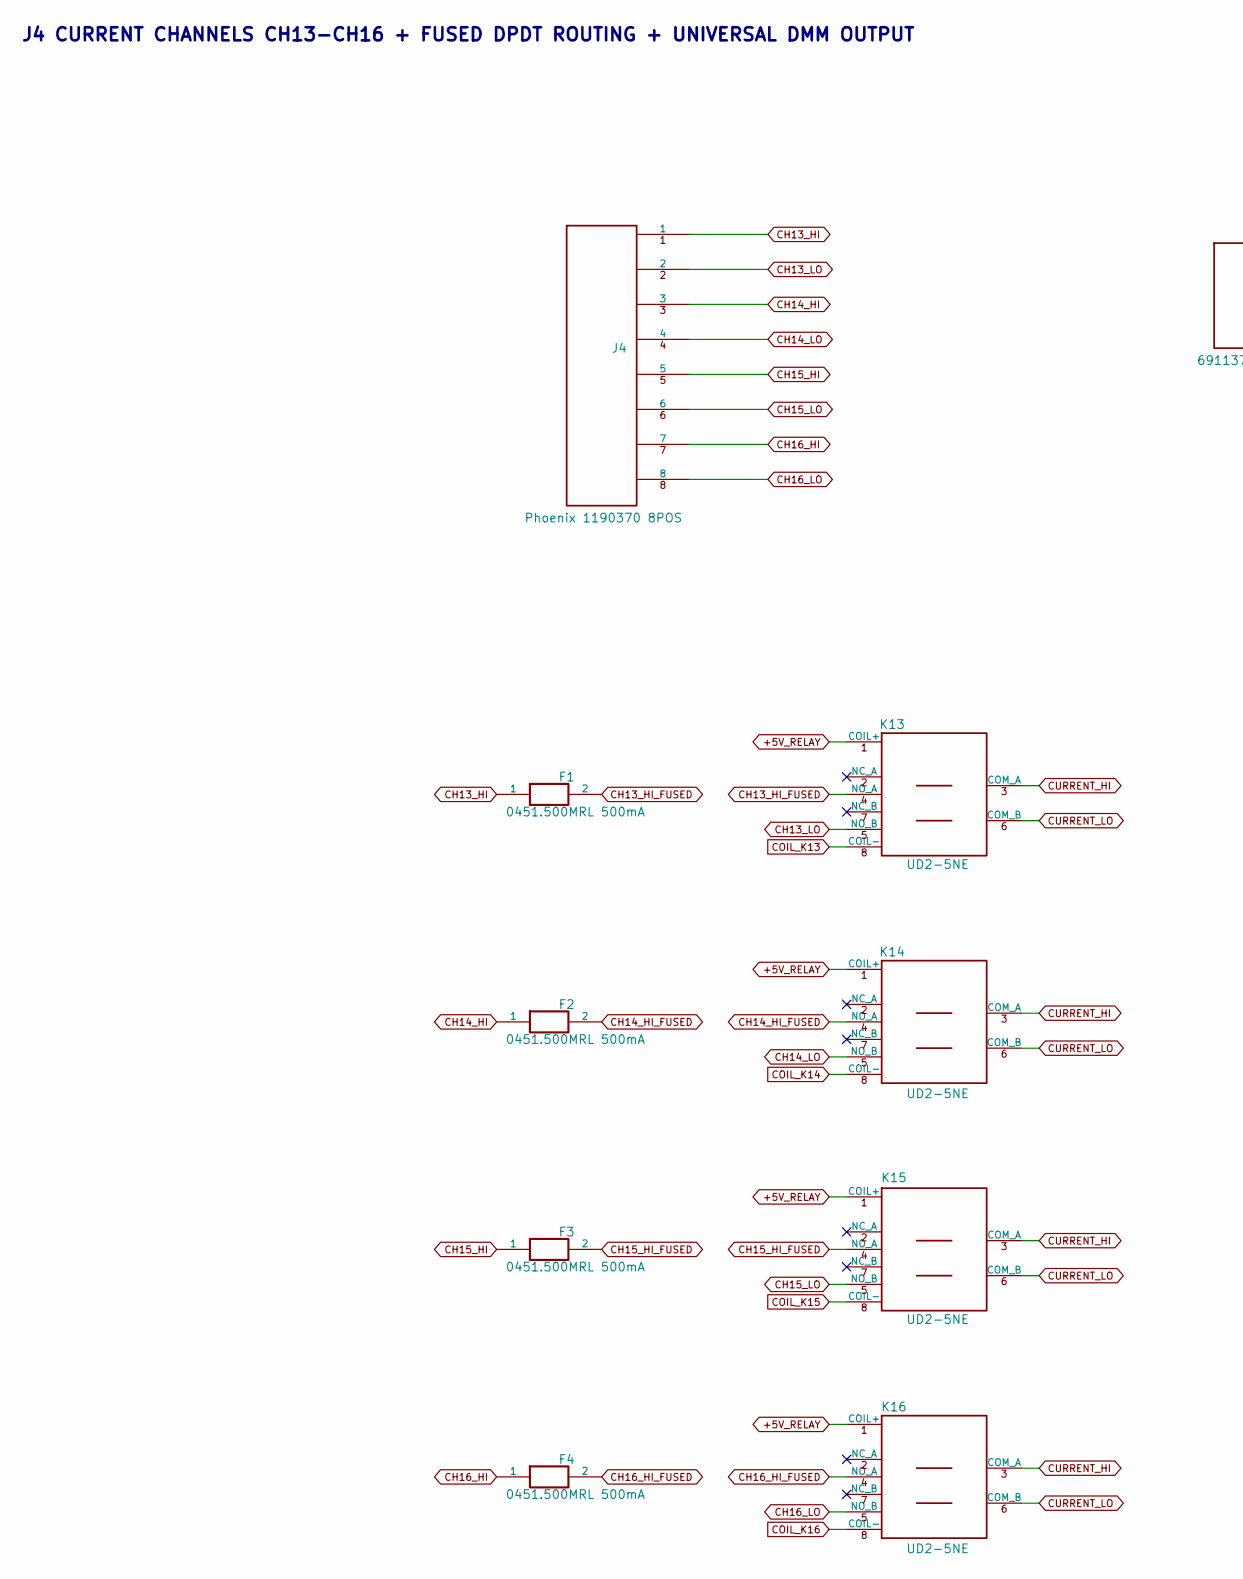
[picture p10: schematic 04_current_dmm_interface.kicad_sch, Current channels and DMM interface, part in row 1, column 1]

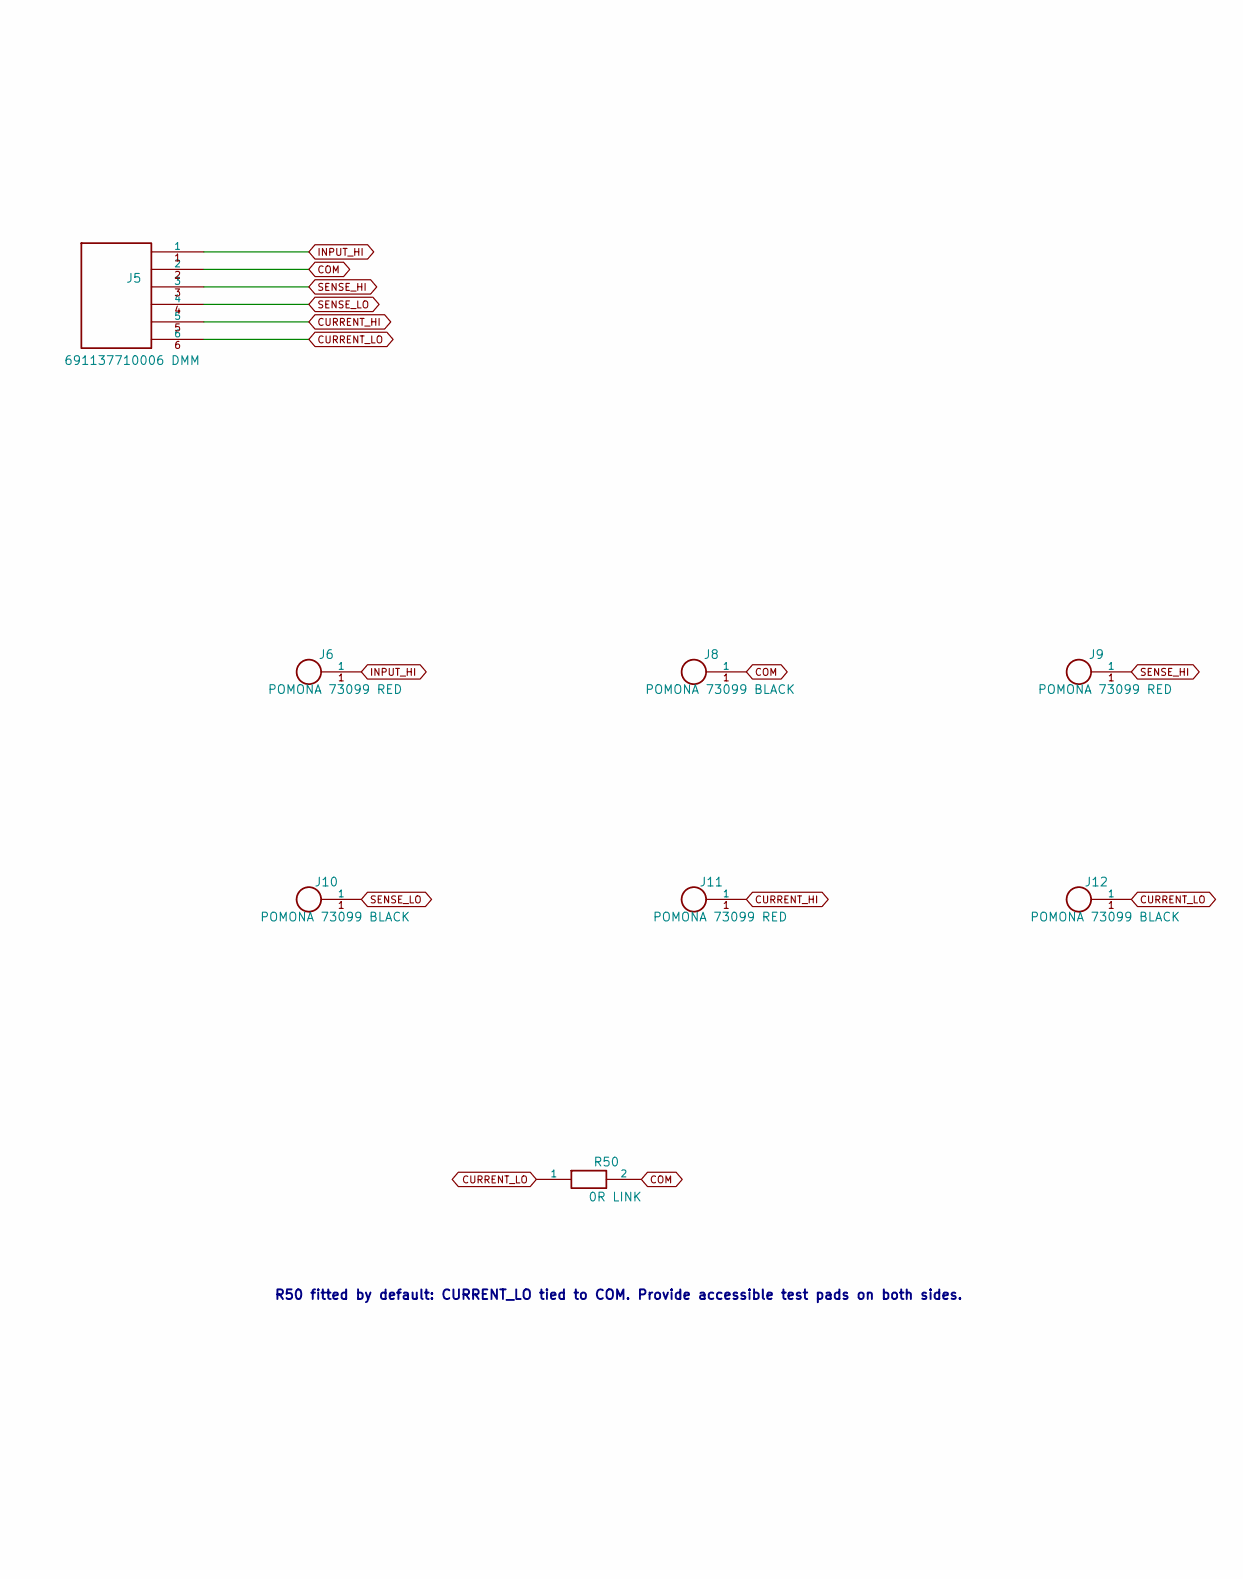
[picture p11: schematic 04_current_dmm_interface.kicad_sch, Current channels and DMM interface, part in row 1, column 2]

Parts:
F1, F2, F3, F4: 0451.500MRL 500mA; Fuse_Littelfuse_0451_NANO2_2410
J4: Phoenix 1190370 8POS; Phoenix_1190370_LPTA-2.5-8-5.0_16THT_Paired
J5: 691137710006 DMM; J_Wurth_WR-TBL_691137710006
J6, J9, J11: POMONA 73099 RED; Pomona_73099_RightAngle_SafetyJack
J8, J10, J12: POMONA 73099 BLACK; Pomona_73099_RightAngle_SafetyJack
K13, K14, K15, K16: UD2-5NE; Relay_KEMET_UD2_NE
R50: 0R LINK; R_0805_2012Metric

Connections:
+5V_RELAY: K13.1 (COIL+), K14.1 (COIL+), K15.1 (COIL+), K16.1 (COIL+); also elsewhere on the board
CH13_HI: F1.1, J4.1
CH13_HI_FUSED: F1.2, K13.4 (NO_A)
CH13_LO: J4.2, K13.5 (NO_B)
CH14_HI: F2.1, J4.3
CH14_HI_FUSED: F2.2, K14.4 (NO_A)
CH14_LO: J4.4, K14.5 (NO_B)
CH15_HI: F3.1, J4.5
CH15_HI_FUSED: F3.2, K15.4 (NO_A)
CH15_LO: J4.6, K15.5 (NO_B)
CH16_HI: F4.1, J4.7
CH16_HI_FUSED: F4.2, K16.4 (NO_A)
CH16_LO: J4.8, K16.5 (NO_B)
COIL_K13: K13.8 (COIL-); also elsewhere on the board
COIL_K14: K14.8 (COIL-); also elsewhere on the board
COIL_K15: K15.8 (COIL-); also elsewhere on the board
COIL_K16: K16.8 (COIL-); also elsewhere on the board
COM: J5.2, J8.1, R50.2; also elsewhere on the board
CURRENT_HI: J5.5, J11.1, K13.3 (COM_A), K14.3 (COM_A), K15.3 (COM_A), K16.3 (COM_A)
CURRENT_LO: J5.6, J12.1, K13.6 (COM_B), K14.6 (COM_B), K15.6 (COM_B), K16.6 (COM_B), R50.1
INPUT_HI: J5.1, J6.1; also elsewhere on the board
SENSE_HI: J5.3, J9.1; also elsewhere on the board
SENSE_LO: J5.4, J10.1; also elsewhere on the board

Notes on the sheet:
R50 fitted by default: CURRENT_LO tied to COM. Provide accessible test pads on both sides.
J4 CURRENT CHANNELS CH13-CH16 + FUSED DPDT ROUTING + UNIVERSAL DMM OUTPUT

Board: 4 copper layers, 117 parts (0 on the bottom side), 106 nets, no tracks yet.

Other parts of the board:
H1, H2, H3, H4: MountingHole_3.20mm

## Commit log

2026-09-28 Add KiCad schematic and design documentation
    [01_power_control.kicad_sch, 02_relay_drivers.kicad_sch, 03_voltage_channels.kicad_sch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]
2026-09-29 Add Phoenix 1190370 connector footprint
    [01_power_control.kicad_sch, 02_relay_drivers.kicad_sch, 03_voltage_channels.kicad_sch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]
2026-09-29 Import XIAO and Wurth vendor footprints
    [01_power_control.kicad_sch, 04_current_dmm_interface.kicad_sch]
2026-09-29 Add manufacturer-specific component footprints
2026-09-29 Assign custom footprints to schematic components
    [01_power_control.kicad_sch, 03_voltage_channels.kicad_sch, 04_current_dmm_interface.kicad_sch]
2026-09-29 Prepare four-layer PCB for component placement
    [BenchScan_DMMX16.kicad_pcb]
2026-09-30 Update preliminary component placement
    [BenchScan_DMMX16.kicad_pcb]
2026-09-30 Hide schematic description fields
    [01_power_control.kicad_sch, 02_relay_drivers.kicad_sch, 03_voltage_channels.kicad_sch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]
2026-10-01 Align MOSFET symbol pins to schematic grid
    [01_power_control.kicad_sch, 02_relay_drivers.kicad_sch]
2026-10-01 Optimize relay driver placement
    [BenchScan_DMMX16.kicad_pcb]
2026-10-01 Correct J1-J4 Phoenix terminal footprints
    [03_voltage_channels.kicad_sch, 04_current_dmm_interface.kicad_sch, BenchScan_DMMX16.kicad_pcb]
2026-10-01 Add corner mounting holes
    [BenchScan_DMMX16.kicad_pcb]
2026-10-05 Restore complete PCB 3D visualization
    [BenchScan_DMMX16.kicad_pcb]
2026-10-05 Propagate corrected component 3D models
    [54-00129.STEP, BenchScan_DMMX16.kicad_pcb, Seeed Studio XIAO ESP32-C6.step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]
2026-10-05 Correct Pomona 73099 connector footprints
    [73099-0.stp, BenchScan_DMMX16.kicad_pcb]
2026-10-05 Refine PCB component placement
    [BenchScan_DMMX16.kicad_pcb]
